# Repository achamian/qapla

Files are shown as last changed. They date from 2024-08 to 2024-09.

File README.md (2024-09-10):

# Qapla

## Qapla 60 key keyboard

Qapla is a 60 key keyboard with Choc or MX switches inspired by Lilly58 and Sofle. Columns have splay and stagger based on my cardboard mocks.

For designing the layout it uses

* [Ergogen](https://github.com/ergogen/ergogen) to define layout, generate PCB and case.
* [Ceoloide Footprints](https://github.com/achamian/ergogen-footprints/tree/diode_via_connections) to add footprints (It is a fork which adds via pads for diodes).
* Routing is done in KiCad.

## Components and Jumpers

### MCU

* Solder jumpers on the front if controller is mounted on top of the pcb facing it
* Solder jumpers on the back if controller is mounted on top of the pcb facing away from it
* Solder jumpers on the back if controller is mounted under the pcb facing it
* Solder jumpers on the front if controller is mounted under the pcb facing away from it

## Display

Qapla supports Nice!View reversible footprint. To use I2C OLED display instead of Nice!View connect display to inner four pins on the left half and outer four pins on the right half. Bridge jumpers on the opposite side of the display.

### JST Battery Connector

Bridge jumpers on the opposite side of the connector. Note the polarity when connecting the battery.

## Bill of Materials

| Quantity | Component | Notes |
|---|---|---|
| 2 | PCB | Left and right halves |
| 2 | Pro Micro compatible MCU | e.g., Nice!Nano for wireless |
| 60 | Choc or MX switches | Depending on preference |
| 60 | Diodes (1N4148 or similar) | SOD-123 |
| 2 | Reset switches | |
| 2 | JS102011SAQN SMT slide switch | |
| 2 | Nice!View or OLED displays | Optional |
| 56 | Keycaps 1u | Compatible with chosen switches |
| 4 | Keycaps 1.5u | Compatible with chosen switches |
| 10 | M2 3mm screws | For case assembly |
| 10 | M2 heat inserts OD: 3.2mm, Length: 3mm | For case assembly [AliExpress](https://vi.aliexpress.com/item/1005003582355741.html)|
| 2 | Blue SMD standard LED | 0805(2012 metric) - Optional - Battery Indicator|
| 2 | 220 Ohm SMD resistors | 0805(2012 metric) - Optional - Battery Indicator|

## Links

* [Introduction to Ergogen](https://flatfootfox.com/ergogen-introduction/)
* [ZMK Keymap Editor](https://nickcoutsos.github.io/keymap-editor/)
* [Keymap Layout Tool](https://nickcoutsos.github.io/keymap-layout-tools/)

## Firmware

* ZMK Firmware is in a [sister repository](https://github.com/achamian/qapla-zmk-config)

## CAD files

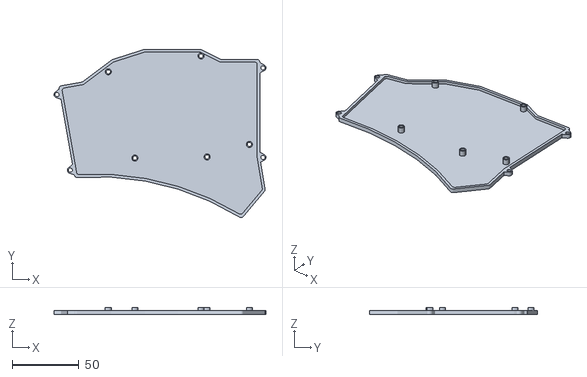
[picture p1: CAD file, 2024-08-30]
v1/case/choc/bottom.stl
158.9 x 126.1 x 5.00

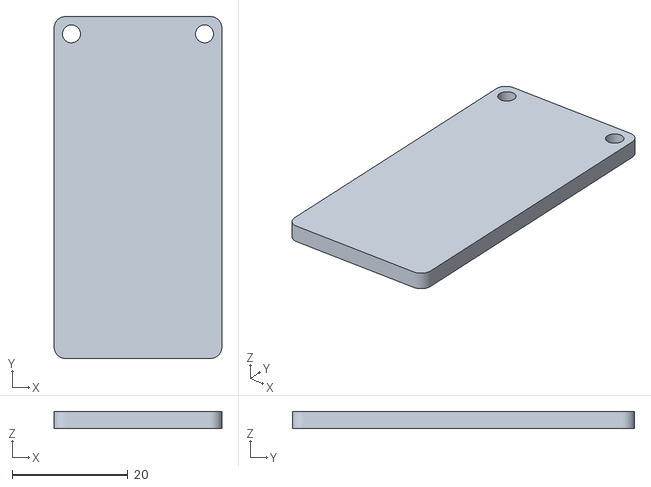
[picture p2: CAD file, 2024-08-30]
v1/case/mx/oled_cover_plate.stl
28.9 x 59.0 x 3.00

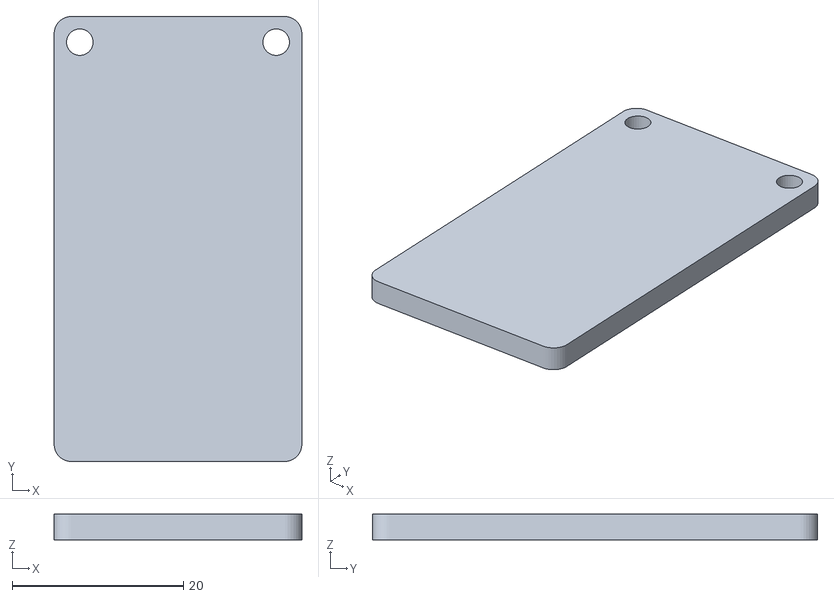
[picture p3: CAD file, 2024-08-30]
v1/case/choc/oled_cover_plate.stl
28.9 x 52.0 x 3.00

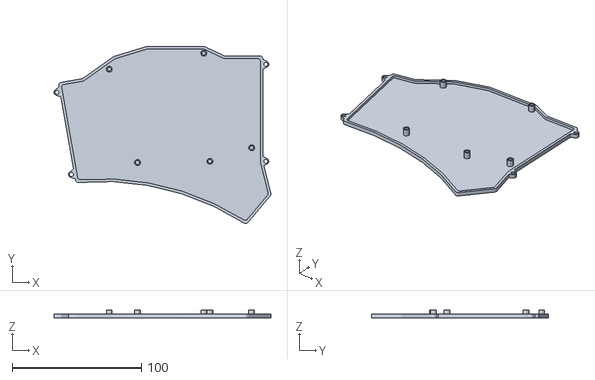
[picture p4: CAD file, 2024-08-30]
v1/case/mx/bottom.stl
167.9 x 137.2 x 6.00

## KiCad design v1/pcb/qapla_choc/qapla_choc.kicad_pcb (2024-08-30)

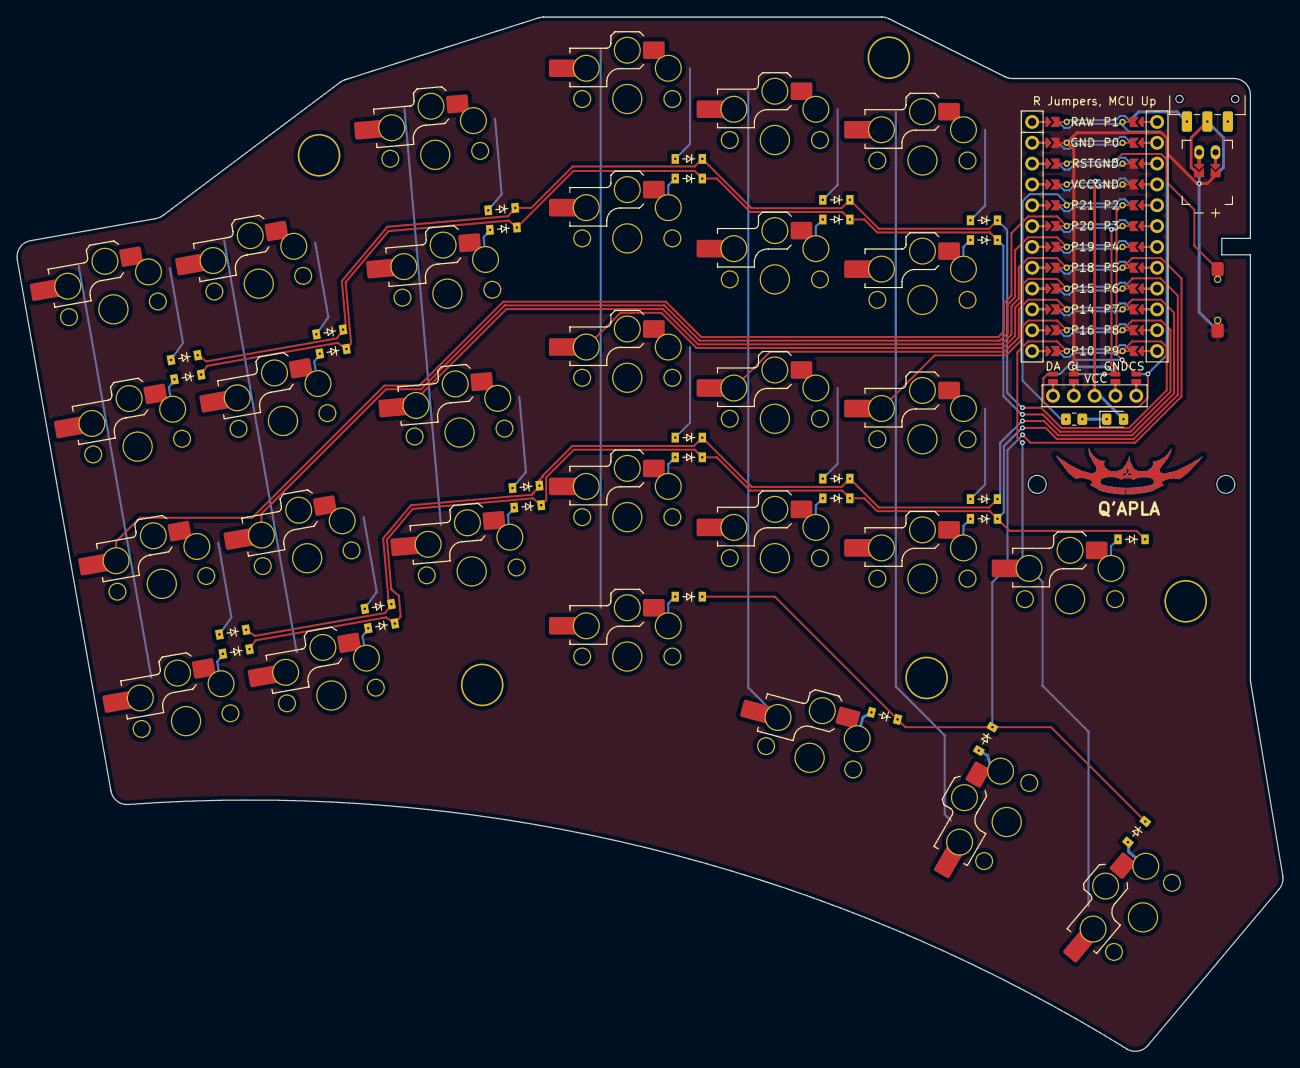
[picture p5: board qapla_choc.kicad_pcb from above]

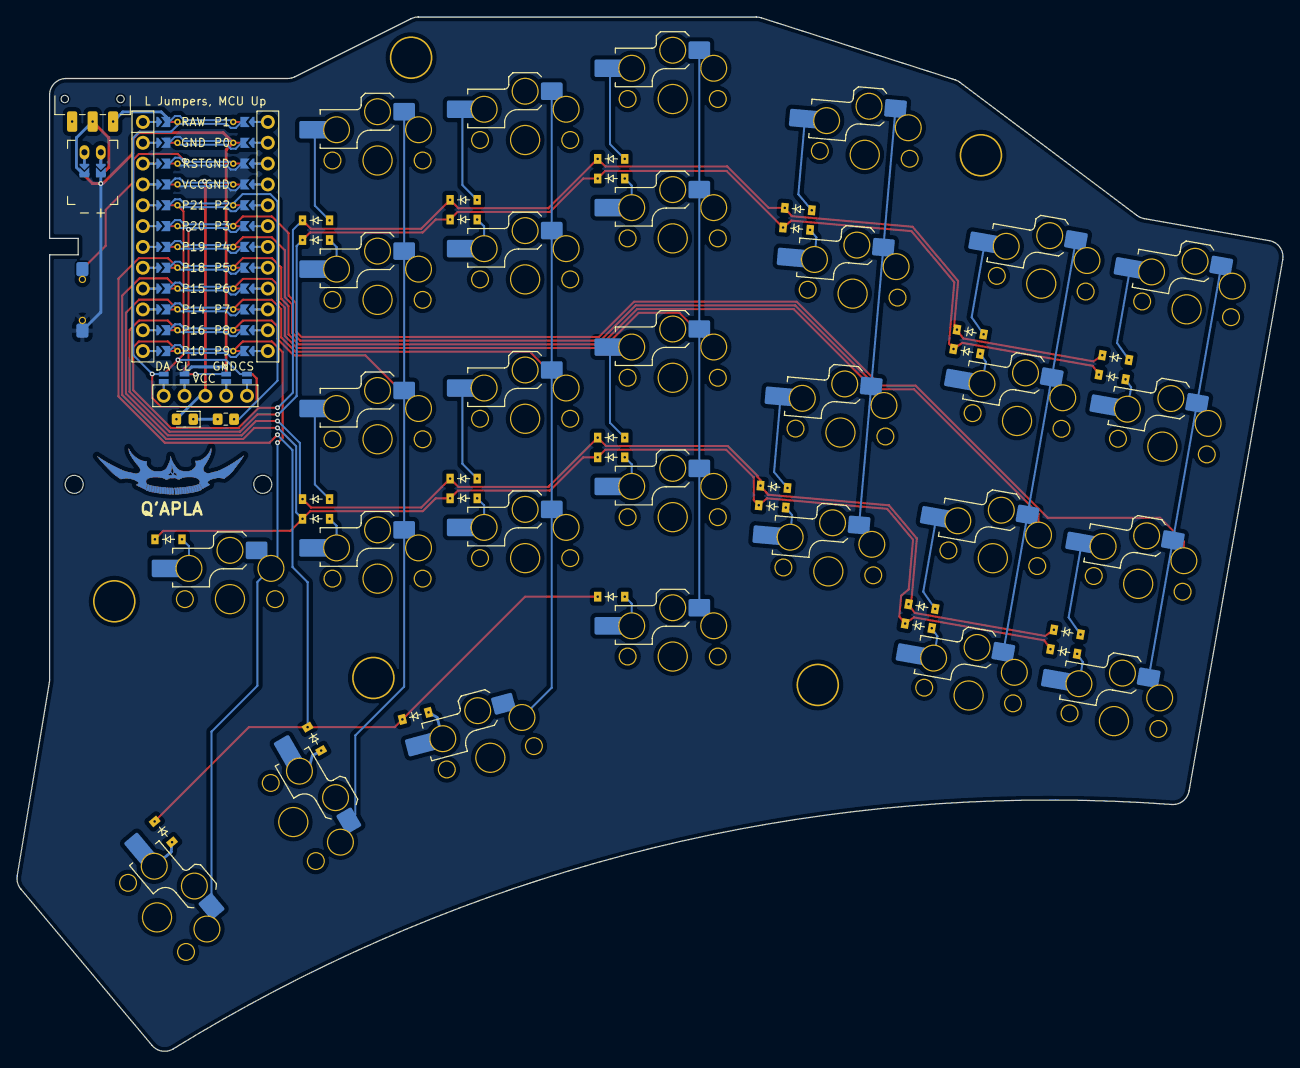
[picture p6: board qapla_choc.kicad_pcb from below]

Board: 2 copper layers, 154.4 x 126.1 mm, 72 parts (58 on the bottom side), 57 nets.

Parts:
D1, D2, D3, D4, D5, D6, D7, D8, D9, D10, D11, D12, D13, D14, D15, D16, D17, D18, D19, D20, D21, D22, D23, D24, D25, D26, D27, D28, D29: diode_tht_sod123
DISP1: display_nice_view
H1, H2, H3, H4, H5: mounting_hole_plated
JST1: battery_connector_jst_ph_2
MCU1: mcu_nice_nano
MH1, MH2: mounting_hole_npth
S1, S2, S3, S4, S5, S6, S7, S8, S9, S10, S11, S12, S13, S14, S15, S16, S17, S18, S19, S20, S21, S22, S23, S24, S25, S26, S27, S28, S29: switch_choc_v1_v2
_1: reset_switch
_2: switch_JS102011SAQN
_3: D_0805_2012Metric_Pad1.15x1.40mm_HandSolder
_3#2: R_0805_2012Metric_Pad1.20x1.40mm_HandSolder

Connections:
BAT_P: JST1.1, _2.2
DISP1_1: DISP1.1, DISP1.10, DISP1.23
DISP1_2: DISP1.2, DISP1.11, DISP1.22
DISP1_4: DISP1.4, DISP1.12, DISP1.21
DISP1_5: DISP1.5, DISP1.13, DISP1.20
GND: DISP1.15, DISP1.25, JST1.2, MCU1.103, MCU1.104, MCU1.123, _1.1, _1.3
JST1_1: JST1.11, JST1.21, JST1.31
JST1_2: JST1.12, JST1.22, JST1.32
P1: DISP1.14, DISP1.24, MCU1.101
P2: DISP1.17, DISP1.27, MCU1.105
P3: DISP1.16, DISP1.26, MCU1.106
P5: D19.1, D27.1, D28.1, D29.1, MCU1.108
P6: D13.1, D15.1, D17.1, D20.1, D22.1, D24.1, D26.1, MCU1.109
P7: D1.1, D3.1, D5.1, D7.1, D9.1, D11.1, MCU1.110
P8: D14.1, D16.1, D18.1, D21.1, D23.1, D25.1, MCU1.111
P9: D2.1, D4.1, D6.1, D8.1, D10.1, D12.1, MCU1.112
P10: MCU1.113, S26.1, S29.1
P14: MCU1.115, S18.1, S19.1, S20.1, S21.1, S27.1
P15: MCU1.116, S13.1, S14.1, S15.1, S16.1, S17.1
P16: MCU1.114, S22.1, S23.1, S24.1, S25.1, S28.1
P18: MCU1.117, S9.1, S10.1, S11.1, S12.1
P19: MCU1.118, S5.1, S6.1, S7.1, S8.1
P20: MCU1.119, S1.1, S2.1, S3.1, S4.1
P21: MCU1.120, _3#2.3
RAW: MCU1.124, _2.3
RST: MCU1.122, _1.2, _1.4
VCC: DISP1.3, MCU1.121, _3.2
_3_1: _3.1, _3#2.4
alt_mod: D27.2, S27.2
index_bottom: D22.2, S18.2
index_home: D9.2, S19.2
index_num: D10.2, S21.2
index_top: D23.2, S20.2
inner_bottom: D24.2, S22.2
inner_far_bottom: D26.2, S26.2
inner_home: D11.2, S23.2
inner_mod: D28.2, S28.2
inner_num: D12.2, S25.2
inner_top: D25.2, S24.2
middle_bottom: D20.2, S14.2
middle_home: D7.2, S15.2
middle_mod: D19.2, S13.2
middle_num: D8.2, S17.2
middle_top: D21.2, S16.2
outer_bottom: D13.2, S1.2
outer_home: D1.2, S2.2
outer_mod: D29.2, S29.2
outer_num: D2.2, S4.2
outer_top: D14.2, S3.2
pinky_bottom: D15.2, S5.2
pinky_home: D3.2, S6.2
pinky_num: D4.2, S8.2
pinky_top: D16.2, S7.2
ring_bottom: D17.2, S9.2
ring_home: D5.2, S10.2
ring_num: D6.2, S12.2
ring_top: D18.2, S11.2

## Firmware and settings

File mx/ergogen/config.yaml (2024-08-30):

units:
  kx: u
  ky: u
  padding: 3
  px: kx + padding
  py: ky + padding
  fillet: 2
  mx_cutout: 14

  mcu_x: 18
  mcu_y: 35
  mcu_p: 1.5
  padding_outside_mcu: 8.5

  wall_thickness: 2

  $default_width: u
  $default_height: u
points:
  zones:
    matrix:
      # Fix placement on KiCAD sheet.
      anchor:
        shift: [100, -150]
      key:
        padding: 1ky
        spread: 1kx
        tags: [1u, key]
      rotate: 10
      columns:
        outer:
          key:
            column_net: P20
          rows.mod.skip: true
        pinky:
          key:
            column_net: P19
          rows.mod.skip: true
        ring:
          key:
            stagger: 12
            splay: -5
            column_net: P18
          rows.mod.skip: true
        middle:
          key:
            stagger: 5
            splay: -5
            column_net: P15
        index:
          key:
            stagger: -5
            column_net: P14
          rows.mod.skip: true
        inner:
          key:
            stagger: -2.5
            column_net: P16
          rows.mod.skip: true
        inner_far:
          key:
            stagger: -2.5
            skip: true
            column_net: P10
          rows:
            bottom.skip: false
      rows:
        mod:
          row_net: P5
        bottom:
          row_net: P6
        home:
          row_net: P7
        top:
          row_net: P8
        num:
          row_net: P9
    thumb:
      key:
        padding: 1ky
        spread: 1kx
        shift: [6, -6]
      anchor:
        ref: matrix_index_mod
      columns:
        alt:
          key:
            splay: -15
            tags: [1u, key]
            column_net: P14
        inner:
          key:
            splay: -15
            rotate: 90
            spread: 1.5kx
            tags: [15u, key]
            column_net: P16
        outer:
          key:
            splay: -10
            rotate: 90
            spread: 1.25kx
            shift: [5, -7]
            tags: [15u, key]
            column_net: P10
      rows:
        mod:
          row_net: P5
    mount_points:
      anchor:
        shift: [100, -150]
      key:
        height: 2
        width: 2
        tags: [hole]
      columns:
        hole1:
          key:
            shift: [2kx, 6ky]
        hole2:
          key:
            shift: [2.15kx, 2.2ky]
        hole3:
          key:
            shift: [3.85kx, 6.65ky]
        hole4:
          key:
            shift: [3.1kx, 2.25ky]
        hole5:
          key:
            shift: [3.8kx, 2.8ky]
outlines:
  _switches:
    - what: rectangle
      where: /key/
      size: mx_cutout
      bound: false
  _switch_plate:
    - what: polygon
      operation: stack
      points:
        - ref: matrix_outer_num
          shift: [-0.5px, 0.5py]
        - ref: matrix_pinky_num
          shift: [-0.5px, 0.5py]
        - ref: matrix_ring_num
          shift: [-0.5px, 0.5py]
        - ref: matrix_middle_num
          shift: [-0.5px, 0.5py]
        - ref: matrix_middle_num
          shift: [1.5px, 0.5py]
        - ref: matrix_inner_num
          shift: [0.5px, 0.5py]
        - ref: matrix_inner_far_bottom
          shift: [-0.5px + padding, 0.5py]
        - ref: matrix_inner_far_bottom
          shift: [mcu_x + 2mcu_p + padding_outside_mcu + padding - 0.5px, 0.5py]
        - ref: matrix_inner_far_bottom
          shift: [mcu_x + 2mcu_p + padding_outside_mcu + padding - 0.5px, -0.5py]
        - ref: thumb_outer_mod
          shift: [0.75ky + 0.5padding, -0.5px]
        - ref: thumb_outer_mod
          shift: [-0.75ky - 0.5padding, -0.5px]
        - ref: matrix_outer_bottom
          shift: [-0.5px, -0.5py]
    - what: circle
      radius: 203.5
      where:
        ref: matrix_middle_mod
        shift: [-46, -221]
      operation: subtract
  plate:
    - name: _switch_plate
      fillet: fillet
    - name: _switches
      operation: subtract
  _keycaps1u:
    - what: rectangle
      where: /1u/
      size: [kx-0.5, ky-0.5]
  _keycaps15u:
    - what: rectangle
      where: /15u/
      size: [1.5kx-0.5, 1ky-0.5]
  _all_keycaps: [+_keycaps1u, +_keycaps15u]
  _mcu:
    - what: rectangle
      size: [mcu_x, mcu_y]
      where:
        ref: matrix_inner_num
      adjust:
        shift: [0.5px + 0.5mcu_x + mcu_p, 0.5py - 0.5mcu_y - 0.5]
  _pcb_outline:
    - name: _switch_plate
    - what: polygon
      operation: add
      points:
        - ref: matrix_inner_num
          shift: [0.5px, 0.5py]
        - ref: matrix_inner_num
          shift: [0.5px + mcu_x + 2mcu_p + padding_outside_mcu, 0.5py]
        - ref: matrix_inner_bottom
          shift: [0.5px + mcu_x + 2mcu_p + padding_outside_mcu, -0.5py]
        - ref: matrix_inner_far_bottom
          shift: [-0.5px, -0.5py]
  pcb:
    - name: _pcb_outline
      fillet: fillet
    - what: rectangle
      operation: subtract
      size: [7, 2]
      where:
        - ref: matrix_inner_num
          shift: [0.5px + mcu_x + 2mcu_p + padding_outside_mcu, -0.5py - 0.5]
  _tilt_handle:
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

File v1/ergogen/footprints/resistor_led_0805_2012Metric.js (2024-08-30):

// Description:
//  0805 (2012 Metric) SMD resistor and led placed side by side
module.exports = {
  params: {
    side: 'F',
    VCC: { type: 'net', value: 'VCC' },
    GPIO: { type: 'net', value: 'GPIO' }
  },
  body: p => {
    let local_net = p.local_net("1");
    return `
  (footprint "D_0805_2012Metric_Pad1.15x1.40mm_HandSolder"
    (layer "${p.side}.Cu")
    ${p.at /* parametric position */}
    (property "Reference" "${p.ref}"
      (at 0 0 ${p.r})
      (layer "${p.side}.SilkS")
      ${p.ref_hide}
      (effects (font (size 1 1) (thickness 0.15)))
    )

    (attr smd)

    ${'' /* Front Silk, Courtyand and Fab */}
    (fp_line (start 0.64 -0.96) (end 0.64 0.96) (stroke (width 0.12) (type solid)) (layer "F.SilkS"))
    (fp_line (start 0.64 0.96) (end 3.5 0.96) (stroke (width 0.12) (type solid)) (layer "F.SilkS"))
    (fp_line (start 3.5 -0.96) (end 0.64 -0.96) (stroke (width 0.12) (type solid)) (layer "F.SilkS"))
    (fp_line (start 0.65 -0.95) (end 4.35 -0.95) (stroke (width 0.05) (type solid)) (layer "F.CrtYd"))
    (fp_line (start 0.65 0.95) (end 0.65 -0.95) (stroke (width 0.05) (type solid)) (layer "F.CrtYd"))
    (fp_line (start 4.35 -0.95) (end 4.35 0.95) (stroke (width 0.05) (type solid)) (layer "F.CrtYd"))
    (fp_line (start 4.35 0.95) (end 0.65 0.95) (stroke (width 0.05) (type solid)) (layer "F.CrtYd"))
    (fp_line (start 1.5 -0.3) (end 1.5 0.6) (stroke (width 0.1) (type solid)) (layer "F.Fab"))
    (fp_line (start 1.5 0.6) (end 3.5 0.6) (stroke (width 0.1) (type solid)) (layer "F.Fab"))
    (fp_line (start 1.8 -0.6) (end 1.5 -0.3) (stroke (width 0.1) (type solid)) (layer "F.Fab"))
    (fp_line (start 3.5 -0.6) (end 1.8 -0.6) (stroke (width 0.1) (type solid)) (layer "F.Fab"))
    (fp_line (start 3.5 0.6) (end 3.5 -0.6) (stroke (width 0.1) (type solid)) (layer "F.Fab"))

    ${'' /* Back Silk, Courtyand and Fab */}
    (fp_line (start 0.64 -0.96) (end 0.64 0.96) (stroke (width 0.12) (type solid)) (layer "B.SilkS"))
    (fp_line (start 0.64 0.96) (end 3.5 0.96) (stroke (width 0.12) (type solid)) (layer "B.SilkS"))
    (fp_line (start 3.5 -0.96) (end 0.64 -0.96) (stroke (width 0.12) (type solid)) (layer "B.SilkS"))
    (fp_line (start 0.65 -0.95) (end 4.35 -0.95) (stroke (width 0.05) (type solid)) (layer "B.CrtYd"))
    (fp_line (start 0.65 0.95) (end 0.65 -0.95) (stroke (width 0.05) (type solid)) (layer "B.CrtYd"))
    (fp_line (start 4.35 -0.95) (end 4.35 0.95) (stroke (width 0.05) (type solid)) (layer "B.CrtYd"))
    (fp_line (start 4.35 0.95) (end 0.65 0.95) (stroke (width 0.05) (type solid)) (layer "B.CrtYd"))
    (fp_line (start 1.5 -0.3) (end 1.5 0.6) (stroke (width 0.1) (type solid)) (layer "B.Fab"))
    (fp_line (start 1.5 0.6) (end 3.5 0.6) (stroke (width 0.1) (type solid)) (layer "B.Fab"))
    (fp_line (start 1.8 -0.6) (end 1.5 -0.3) (stroke (width 0.1) (type solid)) (layer "B.Fab"))
    (fp_line (start 3.5 -0.6) (end 1.8 -0.6) (stroke (width 0.1) (type solid)) (layer "B.Fab"))
    (fp_line (start 3.5 0.6) (end 3.5 -0.6) (stroke (width 0.1) (type solid)) (layer "B.Fab"))

    ${'' /* Pads */}
    (pad "1" thru_hole roundrect (at 1.475 0) (size 1.15 1.4) (drill 0.3) (layers "*.Cu" "*.Paste" "*.Mask") (roundrect_rratio 0.217391) ${local_net.str})
    (pad "2" thru_hole roundrect (at 3.525 0) (size 1.15 1.4) (drill 0.3) (layers "*.Cu" "*.Paste" "*.Mask") (roundrect_rratio 0.217391) ${p.VCC})
  )
  (footprint "R_0805_2012Metric_Pad1.20x1.40mm_HandSolder"
    (layer "${p.side}.Cu")
    ${p.at /* parametric position */}
    (property "Reference" "${p.ref}"
      (at 0 0 ${p.r})
      (layer "${p.side}.SilkS")
      ${p.ref_hide}
      (effects (font (size 1 1) (thickness 0.15)))
    )

    (attr smd)

    ${'' /* Front Silk, Courtyand and Fab */}
    (fp_line (start -2.727064 -0.735) (end -2.272936 -0.735) (stroke (width 0.12) (type solid)) (layer "F.SilkS"))
    (fp_line (start -2.727064 0.735) (end -2.272936 0.735) (stroke (width 0.12) (type solid)) (layer "F.SilkS"))
    (fp_line (start -4.35 -0.95) (end -0.65 -0.95) (stroke (width 0.05) (type solid)) (layer "F.CrtYd"))
    (fp_line (start -4.35 0.95) (end -4.35 -0.95) (stroke (width 0.05) (type solid)) (layer "F.CrtYd"))
    (fp_line (start -0.65 -0.95) (end -0.65 0.95) (stroke (width 0.05) (type solid)) (layer "F.CrtYd"))
    (fp_line (start -0.65 0.95) (end -4.35 0.95) (stroke (width 0.05) (type solid)) (layer "F.CrtYd"))
    (fp_line (start -3.5 -0.625) (end -1.5 -0.625) (stroke (width 0.1) (type solid)) (layer "F.Fab"))
    (fp_line (start -3.5 0.625) (end -3.5 -0.625) (stroke (width 0.1) (type solid)) (layer "F.Fab"))
    (fp_line (start -1.5 -0.625) (end -1.5 0.625) (stroke (width 0.1) (type solid)) (layer "F.Fab"))
    (fp_line (start -1.5 0.625) (end -3.5 0.625) (stroke (width 0.1) (type solid)) (layer "F.Fab"))

    ${'' /* Back Silk, Courtyand and Fab */}
    (fp_line (start -2.727064 -0.735) (end -2.272936 -0.735) (stroke (width 0.12) (type solid)) (layer "B.SilkS"))
    (fp_line (start -2.727064 0.735) (end -2.272936 0.735) (stroke (width 0.12) (type solid)) (layer "B.SilkS"))
    (fp_line (start -4.35 -0.95) (end -0.65 -0.95) (stroke (width 0.05) (type solid)) (layer "B.CrtYd"))
    (fp_line (start -4.35 0.95) (end -4.35 -0.95) (stroke (width 0.05) (type solid)) (layer "B.CrtYd"))
    (fp_line (start -0.65 -0.95) (end -0.65 0.95) (stroke (width 0.05) (type solid)) (layer "B.CrtYd"))
    (fp_line (start -0.65 0.95) (end -4.35 0.95) (stroke (width 0.05) (type solid)) (layer "B.CrtYd"))
    (fp_line (start -3.5 -0.625) (end -1.5 -0.625) (stroke (width 0.1) (type solid)) (layer "B.Fab"))
    (fp_line (start -3.5 0.625) (end -3.5 -0.625) (stroke (width 0.1) (type solid)) (layer "B.Fab"))
    (fp_line (start -1.5 -0.625) (end -1.5 0.625) (stroke (width 0.1) (type solid)) (layer "B.Fab"))
    (fp_line (start -1.5 0.625) (end -3.5 0.625) (stroke (width 0.1) (type solid)) (layer "B.Fab"))

    ${'' /* Pads */}
    (pad "3" thru_hole roundrect (at -3.5 0) (size 1.2 1.4) (drill 0.3) (layers "*.Cu" "*.Paste" "*.Mask") (roundrect_rratio 0.208333) ${p.GPIO})
    (pad "4" thru_hole roundrect (at -1.5 0) (size 1.2 1.4) (drill 0.3) (layers "*.Cu" "*.Paste" "*.Mask") (roundrect_rratio 0.208333) ${local_net.str})
  )
    `;
  }
}

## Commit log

2024-08-22 Define plate
2024-08-22 Plate with keycaps
2024-08-22 Adding space for MCU on the board
2024-08-22 Start building PCB
2024-08-22 Adding ceoloide footprint from a fork
2024-08-22 Creating a KiCad project
    [qapla.kicad_pcb, qapla.kicad_sch]
2024-08-23 Adding mx switch support
    [qapla.kicad_pcb]
2024-08-23 Adding diodes and mcu
    [qapla.kicad_pcb]
2024-08-23 Adding nets for keys, reset switch and display
    [qapla.kicad_pcb]
2024-08-23 Adding JS102011SAQN switch
    [qapla.kicad_pcb]
2024-08-26 Positioning reset switch, jst connector and power switch
    [qapla.kicad_pcb]
2024-08-26 All components in place except mounting holes
    [qapla.kicad_pcb]
2024-08-26 Adding mounting holes
    [qapla.kicad_pcb, qapla_plate.kicad_pcb]
2024-08-26 Adding holes for display plate
    [qapla.kicad_pcb]
2024-08-27 Adding bottom plate
    [bottom_plate.kicad_pcb, qapla.kicad_pcb, qapla_plate.kicad_pcb]
2024-08-27 Moving mount points to board instead of ergogen yaml parent
2024-08-27 Adjusting hole positions
    [qapla.kicad_pcb, qapla_plate.kicad_pcb]
2024-08-28 Starting work on bottom case
    [qapla.kicad_pcb, qapla_plate.kicad_pcb]
2024-08-28 Finalising Plate and PCB design for choc
    [bottom_plate.kicad_pcb, qapla.kicad_pcb, qapla_plate.kicad_pcb]
2024-08-29 Adjusting distance between diodes to accomodate traces
    [qapla.kicad_pcb, qapla_plate.kicad_pcb]
2024-08-29 Adding bottom case
    [bottom.stl, qapla.kicad_pcb]
2024-08-29 Fixing hole size for heat inserts
    [bottom.stl]
2024-08-29 Moving files to choc directory
    [bottom.stl, qapla.kicad_pcb, qapla.kicad_sch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]
2024-08-29 Adding MX footprints and ergogen config
2024-08-29 Renaming kicad project
    [qapla_choc.kicad_pcb, qapla_choc.kicad_sch, qapla_mx.kicad_pcb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]
2024-08-29 Finalize MX case and PCB design
    [bottom.stl, qapla_mx.kicad_pcb, qapla_plate_mx.kicad_pcb]
2024-08-30 Routing MX switches
    [bottom.stl, qapla_mx.kicad_pcb, qapla_plate_mx.kicad_pcb]
2024-08-30 Adding GPIO param to resistor_led_0805_2012Metric footprint
2024-08-30 Finalizing Qapla MX PCB
    [qapla_mx.kicad_pcb]
2024-08-30 Adding OLED cover plate for MX case
    [oled_cover_plate.stl]
2024-08-30 Finalize choc case and pcb design
    [bottom.stl, oled_cover_plate.stl, qapla_choc.kicad_pcb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]
2024-08-30 Changing battery LED net
    [qapla_choc.kicad_pcb]
2024-08-30 MX Keyboard has a batleth
    [qapla_choc.kicad_pcb, qapla_mx.kicad_pcb]
2024-08-30 Choc keyboard routing done
    [qapla_choc.kicad_pcb]
2024-09-03 Merging choc and mx into one config
    [bottom.stl, oled_cover_plate.stl, qapla_choc.kicad_pcb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]
2024-09-03 Add missing components to the BOM
2024-09-03 Update BOM
